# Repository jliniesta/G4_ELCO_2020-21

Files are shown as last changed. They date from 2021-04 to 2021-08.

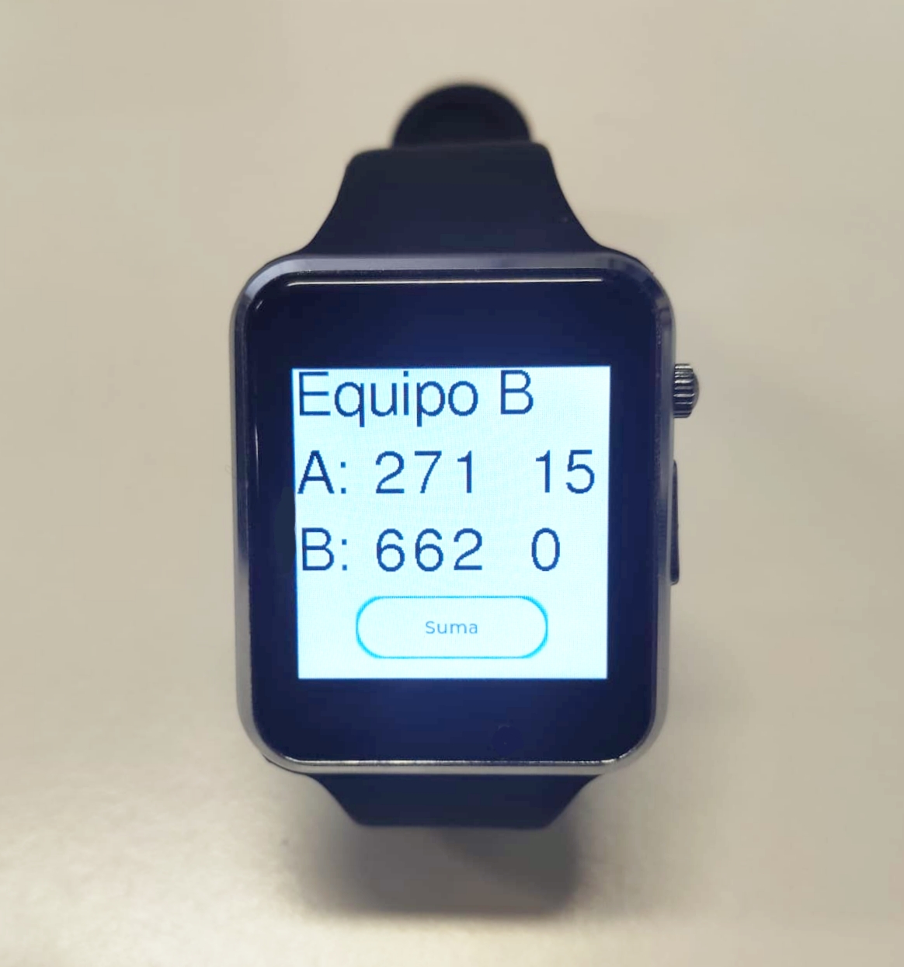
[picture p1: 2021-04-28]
Prototipo/Resultado final prototipo/reloj_TTGO_T-Watch.jpg

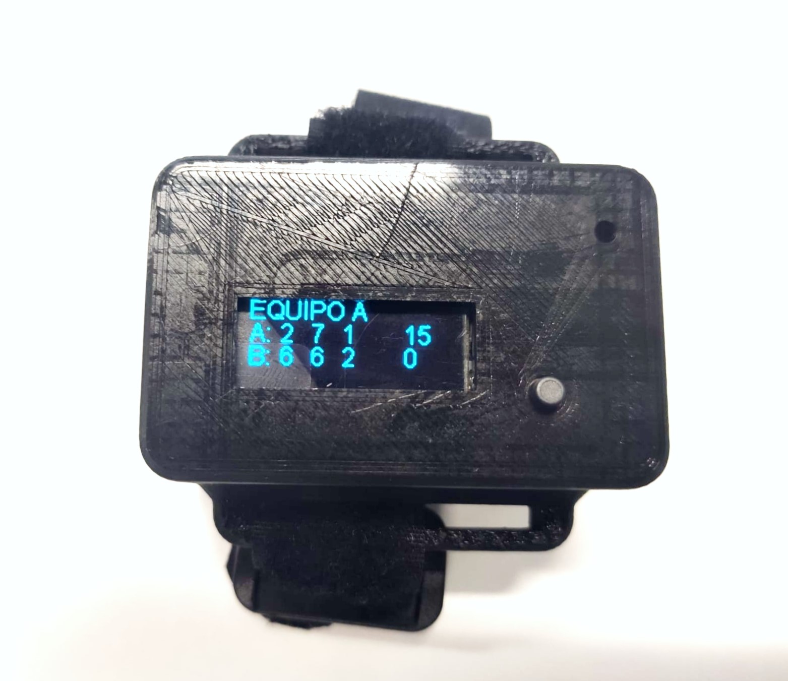
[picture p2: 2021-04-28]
Prototipo/Resultado final prototipo/reloj_heltec.jpg

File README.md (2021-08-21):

# PADEL WATCH

https://padel-watch.webnode.es/

https://blogs.upm.es/tfb/contador-de-pulsos-padel/

Proyecto del grupo 4 de la asignatura de Electrónica de Consumo (ELCO)

ETSIT - UPM

# Funcionamiento
> Marcador para poder contar todos los puntos de un partido de pádel.
> Cada pareja, dispondrá de al menos un reloj que con un pequeño botón,
> que permitirá incrementar los puntos. De forma, que cuando una pareja
> gane un punto, lo único que tendrá que hacer es pulsar el botón y el
> marcador se actualizará con el nuevo resultado.

### Integrantes
- Javier López Iniesta Díaz del Campo
- Fernando García Gutiérrez
- Ivan Martín Cantón
- Iñigo Montesino Sarmiento
- Luis de Pablo Beltrán

### Licencia
Copyright 2021 Padel Watch. \
All rights reserved.

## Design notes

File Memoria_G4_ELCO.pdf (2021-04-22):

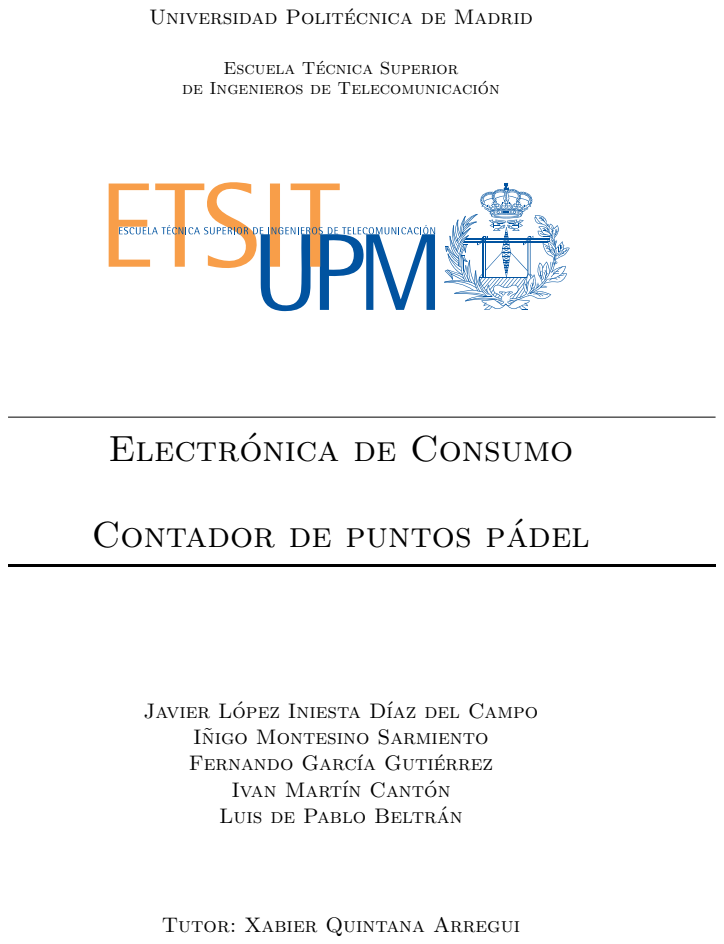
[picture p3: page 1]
Javier Lopez Iniesta D ´; íaz del Campo

Universidad Politecnica de Madrid ´

Escuela Tecnica Superior ´

de Ingenieros de Telecomunicacion´

Electronica de Consumo ´

Contador de puntos padel

Inigo Montesino Sarmiento ˜

Fernando García Gutierrez ´

Ivan Martín Canton´

Luis de Pablo Beltran´

Tutor: Xabier Quintana Arregui

Contador de puntos pádel

## Índice

1. Introducción | 2
2. Idea de producto | 2
3. Prototipo | 3
4. Resultado final del prototipo | 6
5. Producto final | 7
6. Manual de usuario | 10
7. Pagina web | 10

## 1. Introducción

Este proyecto ha sido realizado por 5 alumnos de la asignatura de Electrónica de Consumo del Itinerario de Sistemas Electrónicos del Grado en Ingeniería de Tecnologías y Servicios de Telecomunicación. El objetivo de esta asignatura es realizar un producto que pueda satisfacer una necesidad, que sea atractivo, funcional, y orientado al consumo (más de 10.000 unidades fabricadas). Además, deberá ser viable económicamente.

En este proyecto, se ha trabajado como si fuera una pequeña empresa de ingeniería, pasando por todas las fases de diseño y comercialización del producto. En primer lugar, se desarrollará la idea de servicio y el problema a resolver. Posteriormente, se explicará el prototipo realizado, detallando su completo funcionamiento hardware y software. Por último, presentaremos nuestro diseño final orientado a la producción masiva.

Estos tres pasos los complementaremos con detalles técnicos y orientados a la experiencia del usuario final, redactando su manual de instrucciones respectivo y una pagina web que suponga para el cliente el lugar de adquisición del producto o donde obtener un servicio post-venta.

## 2. Idea de producto

En los últimos años, el pádel es el deporte que más está creciendo en España, tanto a nivel amateur como a nivel profesional. Dentro de este deporte, hemos detectado la necesidad de los usuarios de contar los puntos de una manera más fácil y sin que sea necesario hacer mucho uso de la memoria evitando tanto malentendidos como incertidumbres en el desarrollo del partido.

Por ello, desde nuestra empresa llamada Padel Watch, proponemos crear un marcador para poder contar todos los puntos de un partido de pádel. Cada pareja, dispondrá de una pulsera que contará con un pequeño botón, para incrementar los puntos. De esta forma, cuando una pareja gane un punto, lo único que tendrá que hacer es pulsar el botón y el marcador se actualizará con el nuevo resultado.

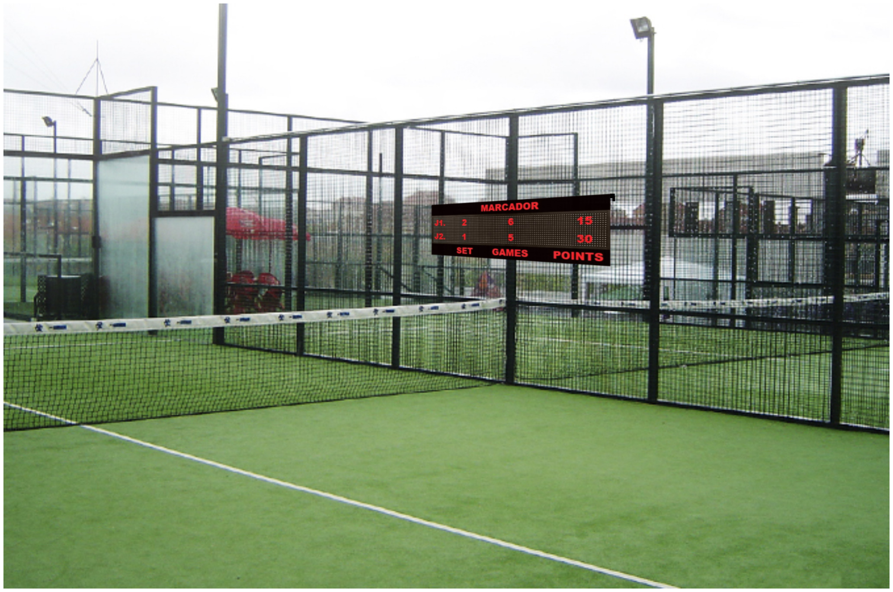
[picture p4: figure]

Figura 1: Marcador pádel

## 3. Prototipo

### 3.1. Materiales y componentes

Para nuestro prototipo se han utilizado la siguiente lista de materiales:

Relojes:

- ESP32 (WiFi Kit 32).
- LilyGO ©TTGO T-Watch-2020 ESP32.

Pantalla: LilyGO TTGO T5 V2.3 ESP32 - with 2.13 inch E-paper E-ink.

Batería: E603048P 4121 (900 mAh).

Pulsador: mcm t05.

Resistencia de 1 kΩ.

Filamento PLA 1.75 mm de color negro.

Correa de velcro

ProtoBoard

En primer lugar, el ESP32 utilizado, ha sido el modelo “WiFi Kit 32” (https://heltec.org/project/wifi-kit-32/) [1], un microcontrolador que cuenta con un display OLED integrado de 0, 96 pulgadas. Además, cuenta con conexión WiFi y Bluetooth.

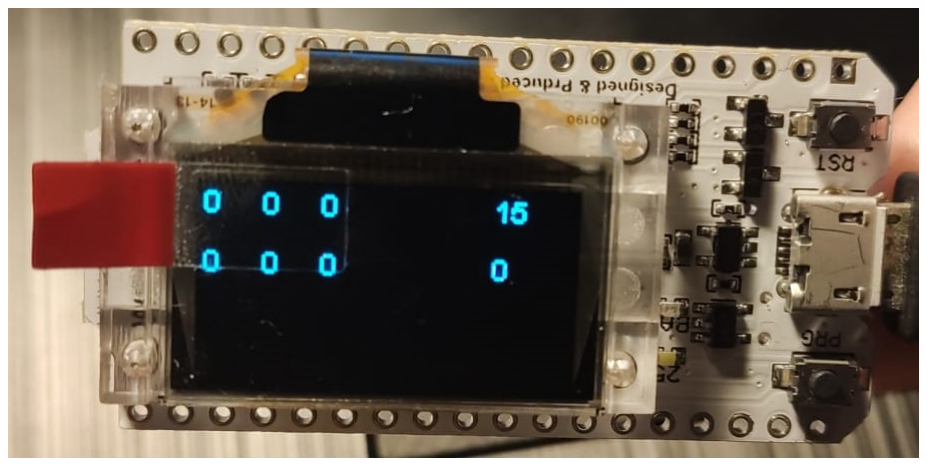
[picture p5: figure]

Figura 2: ESP32 - WiFi Kit 32

Dicho microcontrolador, ha sido adquirido por la Universidad Politécnica de Madrid y cedido para este proyecto. Se puede encontrar fácilmente en el mercado por un precio de alrededor de 20 e. Para poder alimentar el ESP32, necesitamos disponer de una batería. Para ello, hemos elegido una de 900 mAh, concretamente el modelo “E7E6H-D60-1”. (https://www.ebay.es/itm/3-7V-900mAh-603048-Li-po-Polymer-li-ion-Rechargeable-Battery-For-GPS-PSP-mp3-PAD-/111946070348)

Para poder aumentar los puntos desde el ESP32, hemos tenido que incorporar un pulsador “mcm t05”, colocado en el pin 12 junto con una resistencia de 1 kΩ colocada en paralelo y todo ello trabajando sobre la protoboard. Además, para ver como queda en la muñeca le hemos añadido una correa de velcro.

En segundo lugar, también se ha utilizado un reloj programable de la marca LilyGO, que puede interaccionar con el entorno a través de distinto sensores. El modelo elegido, ha sido el “LilyGO TTGO T-Watch-2020 ESP32” (http://www.lilygo.cn/prod_view.aspx?TypeId=50053&Id=1290&FId=t3:50053:3) [2]. Este reloj se puede programar con Arduino, Scratch, micropython, pictoblox, etc.

El reloj cuenta con una pantalla táctil LCD de 1, 54 pulgadas. En adicción, posee una batería de Litio, acelerómetro, vibración, altavoz y sensor de infrarrojos. Se puede interconectar mediante WiFi y Bluetooth. Se puede encontrar en el mercado por unos 25 e. El reloj ha sido cedido por nuestro tutor, Xabier Quintana Arregui.

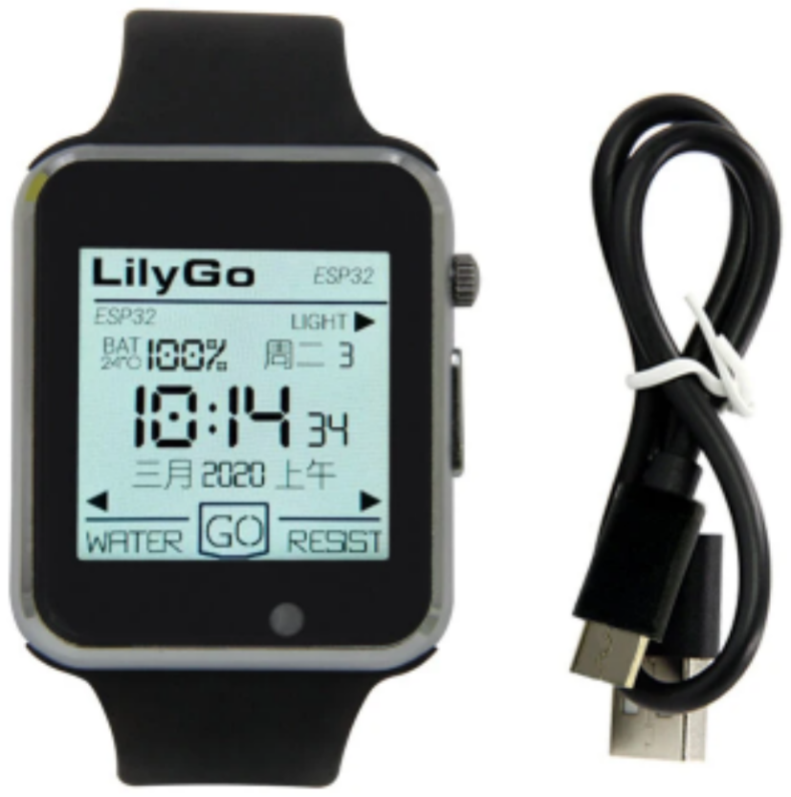
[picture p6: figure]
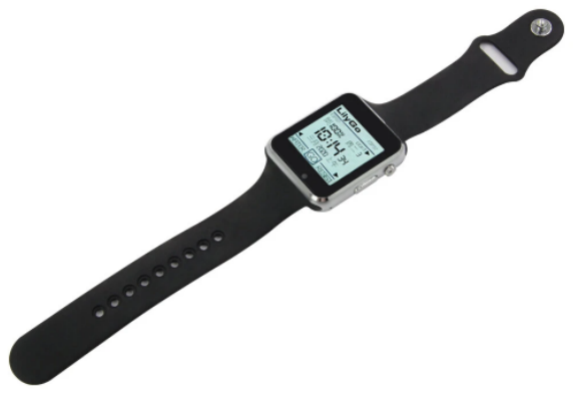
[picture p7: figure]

(a) (b)

Figura 3: LilyGO TTGO T-Watch-2020 ESP32 (a) Pantalla y cableado (b) Reloj completo.

Además, se dispone de una pantalla también de la marca LilyGO (“LilyGO TTGO T5 V2.3 ESP32”) (http://www.lilygo.cn/prod_view.aspx?TypeId=50031&Id=1149&FId=t3:50031:3) [3], de 2,13 pulgadas de tinta electrónica, con un microcontralador basado en un ESP32. Dispone de conexión WiFi y Bluetooth, así como de una batería.

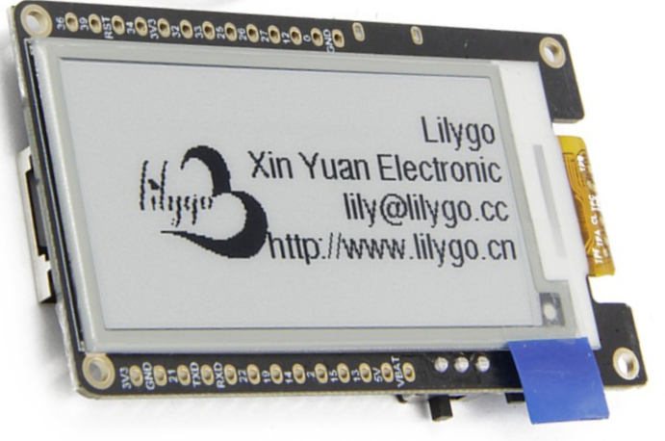
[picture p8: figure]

Figura 4: LilyGO TTGO T5 V2.3 ESP32

### 3.2. Esquemáticos

La Figura 5 se muestra los esquemáticos del prototipo del reloj, formado por el ESP32, la batería, un pulsador y una resistencia. Dicho esquemáticos han sido realizados mediante el programa Fritzing [4].

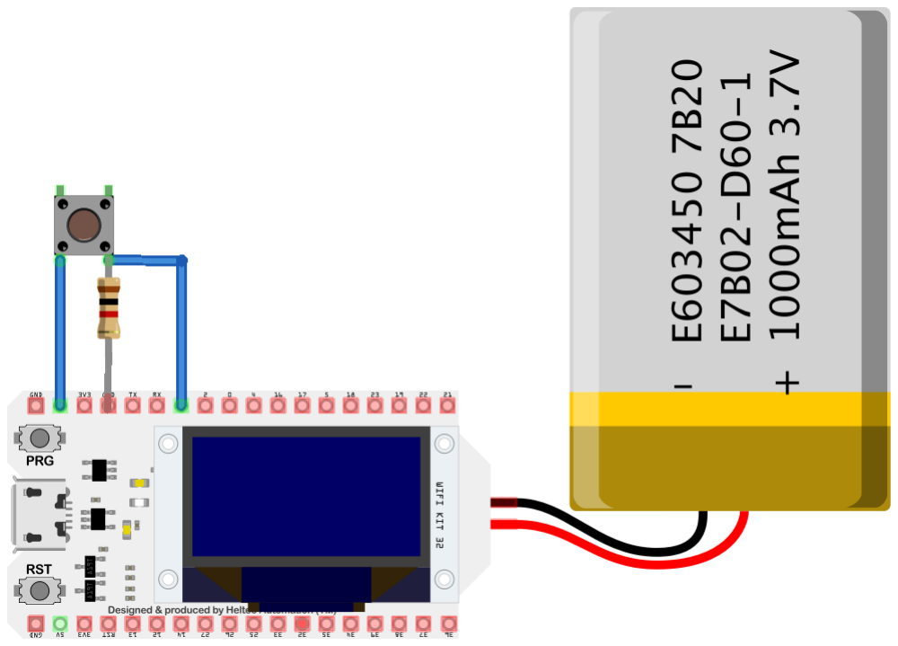
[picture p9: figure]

Figura 5: Esquemáticos del reloj con el ESP32

### 3.3. Diseño e implementación software

Reloj 1 | Reloj 2

## Pantalla

Figura 6: Esquema de la comunicación entre los dispositivos

### 3.4. Diseño mecánico y modelo 3D

A continuación, en la Figura 7 se muestra las carcasas del marcador y del reloj. Para su diseño e implementación, se ha usado la herramienta de FreeCAD 0.18 [5].

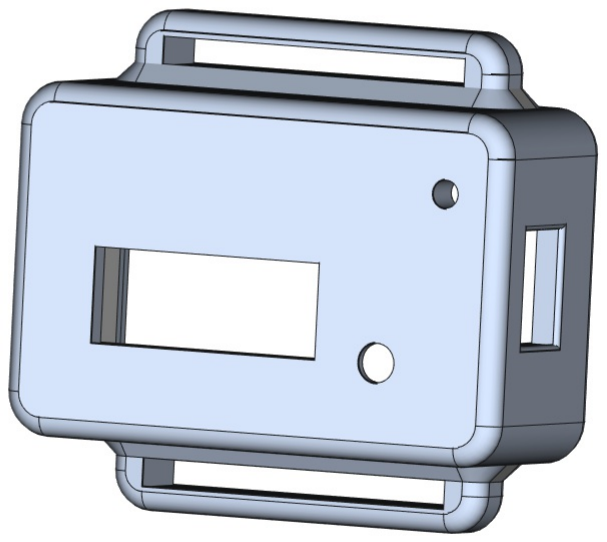
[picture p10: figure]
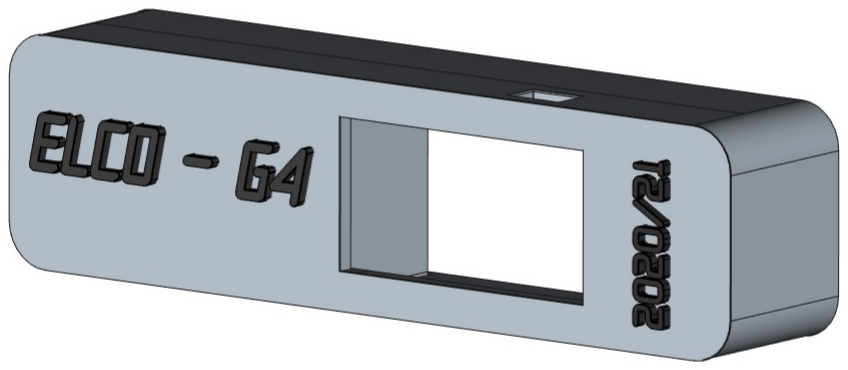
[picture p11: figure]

(a) Marcador | (b) Reloj

Figura 7: Modelo 3d de las carcasas

Además hemos diseñado las siguientes tapas para proteger la parte trasera tanto del reloj como del marcador.

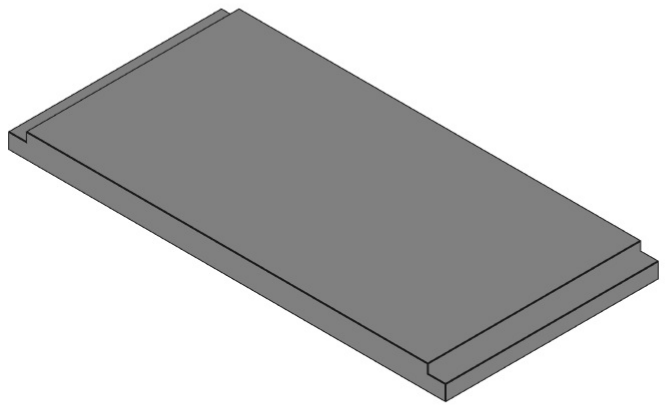
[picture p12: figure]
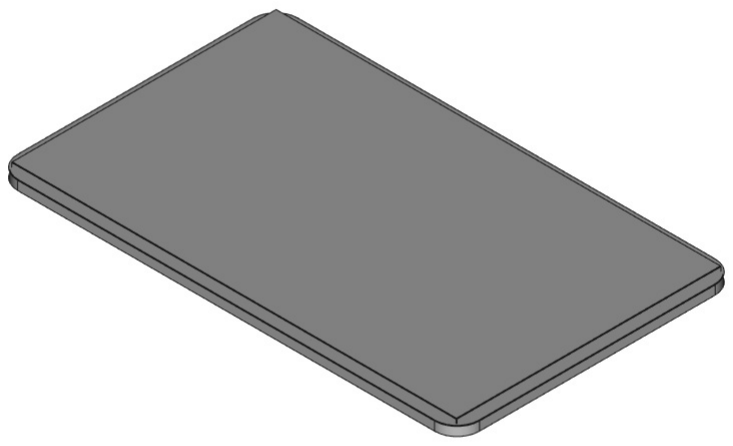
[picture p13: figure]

(a) Marcador | (b) Reloj

Figura 8: Modelo 3d de las tapas de las carcasas

Las carcasas las hemos fabricado mediante una impresora 3D de la ETSIT-UPM. Para la sujeción del reloj le añadiremos la cinta de velcro.

## 4. Resultado final del prototipo

Poner imágenes del resultado final del prototipo.

## 5. Producto final

Tras comprobar que el prototipo creado ha sido desarrollado satisfactoriamente, procedemos a especificar como será nuestro producto final.

El producto final constará de dos relojes LilyGO TTGO T-Watch-2020 ESP32 [2] y un marcador LED electrónico ”VEVOR”[6]. La idea será tener dos relojes igualmente programados que constan con un botón para sumar puntos y otro para deshacer la acción anterior. Ambos estarán conectados entre ellos mediante WiFi y a su vez conectados con el marcador central, que mostrará el resultado del partido constantemente.

### 5.1. Materiales y Suministradores

Como hemos especificado anteriormente, solo contaremos con la necesidad de obtener:

Reloj: LILYGO® TTGO T-Watch-2020 ESP32

Marcador: Rótulo LED Electrónico ”VEVOR”

En primer lugar, el reloj será el mismo que usamos en el prototipo. No profundizaremos en sus especificaciones ya que lo hicimos en la parte del prototipo. Sin embargo, debemos de mencionar a nuestros suministradores, que serán directamente la pagina web www.banggood.com. Además, hemos alcanzado con ellos un descuento por volumen de aproximadamente el 25 % lo que hará que el precio unitario de cada reloj sea de 19e.

Por otro lado tenemos el marcador que pertenece a la marca VEVOR. Es un marcador que adquiriremos a través del distribuidor Amazon, con el que hemos negociado un descuento por volumen de 25 %.

### 5.2. Almacenaje, distribución y medios de venta

Para el producto que vamos a comercializar será necesario tener un sitio para poder llevar a cabo la actividad de embalaje, carga del software y almacenamiento de productos terminados listos para su envío. Por lo tanto para reducir costes, alquilaremos durante nuestro ejercicio económico un espacio coworking [7], en la zona centro de Madrid, a razón de 5.000€ anuales.

La distribución del producto la haremos mediante envíos y servicio de paquetería tradicional, llegando a distintos acuerdos con empresas de mensajería.

Como medio de venta principal contaremos con nuestra página web donde el cliente directamente podrá ejecutar de una manera sencilla la compra. A su vez consideramos entrar en webs externas (Amazon e Ebay) para poder llegar a mas público y poder aumentar el volumen de ventas.

### 5.3. Empaquetado

Con el fin del transporte del producto en perfectas condiciones hemos diseñado una caja para su empaquetado. Dependiendo del paquete de venta elegido, la caja contendrá en su interior los productos, así como un manual de instrucciones. La estimación del coste de empaquetado será de 1 epor unidad. Las dimensiones de la caja serán:

Para los paquetes con marcador: 110 cm x 50 cm x 20 cm

Para los paquetes sin marcador: 30 cm x 30 cm x 30 cm

La Figura 9 muestra el empaquetado del paquete de 2 relojes más marcador.

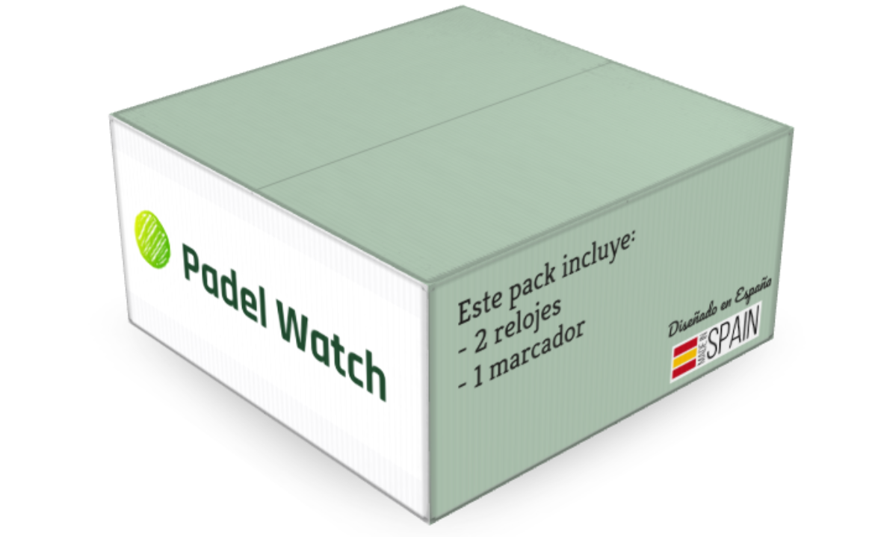
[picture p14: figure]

Figura 9: Empaquetado

### 5.4. Estudio costes y precios de venta

Para realizar el estudio y la viabilidad económica de la empresa, en primer lugar, se ha realizado una estimación del número total de unidades vendidas de nuestros productos. Tendremos tres tipos de productos que el cliente podrá comprar: el paquete de marcador y dos relojes, el paquete de cuatro relojes y el paquete de dos relojes. Estimamos que venderemos 10 000 paquetes, siendo el 75 % de ellos el primero, y un 12,5 % el segundo y tercero.

Paquetes de venta | Estimación unidades vendidas
2 relojes + marcador 2 relojes extra 4 relojes | 7 500 1 250 1 250
Total unidades: | 10 000

Tabla 1: Estimación ventas

Posteriormente, se considerarán los costes materiales de nuestros productos. Como es lógico, llegaremos a acuerdos con los proveedores de relojes y de pantallas para obtener un descuento por volumen de compra de alrededor del 25-30 %. Los otros dos gastos adicionales a tener en cuenta serán los materiales de embalajes, estimados en 1, 00 e por cada paquete, y el lugar donde tendremos nuestra actividad económica, que supondrán los ya mencionados 5 000 e anuales.

En la Tabla 2 se muestran la estimación de costes materiales.

Costes materiales
Producto | Nº de unidades | Precio / unidad | Coste total
Relojes Marcadores Embalaje | 22 500 7 500 10 000 | 19, 00 e 50, 00 e 1, 00 e | 427 500 e 375 000 e 10 000 e
| Total: | | 812 500 e
| Coworking (coste anual): | | 5 000 e
| Total gastos materiales: | | 817 500 e

Tabla 2: Costes materiales

Los siguientes gastos importantes que supondrán para la empresa será la contratación del personal. Hemos estimado que necesitaremos personal para realizar dos labores concretas: la carga del software en cada reloj y el preparado y embalado de todos los paquetes, junto con la responsabilidad de entregarlo a la empresa de paquetería. La carga de trabajo medida en tiempo de estas dos labores será de 6 minutos por cada carga de programa en el reloj y de 30 minutos de embalaje por cada paquete. El perfil de trabajador que buscamos para la carga del software será un diplomado universitario, ingeniero técnico o equivalente, que supondrá para la empresa un gasto total de 19, 36 e por hora trabajada. Para la realización del embalaje y la gestión del envío requeriremos un perfil con un nivel de formación F.P.II-Graduado, escolar o equivalente que supondrán para la empresa un gasto de 16, 00 e por hora trabajada.

Costes personales
Función | Unidades | Tiempo/labor (h) | Total horas | Precio/hora | Coste
Cargar programas Embalaje | 22 500 relojes 10 000 paquetes | 0, 1 0, 5 | 2 250 5 000 | 19, 36 e 16, 00 e | 43 560 e 80 000 e
| | | | Total: | 123 560 e

Tabla 3: Costes personal

En cuanto a los ingresos, como es lógico, cada uno de los paquetes descritos anteriormente tendrá su respectivo precio. Para calcularlo, lo primero que hacemos es estimar cual es el precio por unidad que supone para nosotros cada uno de estos paquetes, y le aplicaremos un 40 % de margen de beneficio. Adicionalmente, para dar el precio final del producto debemos aplicarle el 21 % de I.V.A.

Paquete de venta | Coste/paquete (e) | Precio (sin IVA) | IVA | Precio final
2 relojes + marcador 2 relojes extra 4 relojes | 101, 86 e 51, 86 e 89, 86 e | 142, 60 e 72, 60 e 125, 80 e | 29, 95 e 15, 25 e 26, 42 e | 172, 54 e 87, 84 e 152, 22 e

Tabla 4: Coste producto final

## 6. Manual de usuario

En el manual de usuario se muestran las especificaciones técnicas del reloj y del marcador de los productos comercializados por Padel Watch, asi como las advertencias de seguridad a seguir. Además, se muestra su funcionamiento y una sección de posibles preguntas que le pueden surgir a los usuarios. En el siguiente link de github puede consultar el manual:

Pinche aquí para ver el manual (https://github.com/iniesta99/G4_ELCO_2020-21/blob/main/Dise%C3%B1o%20final/Manual_de_usuario_G4_ELCO.pdf)

## 7. Pagina web

La pagina web ha sido diseñada con una plantilla de Webnode. En ella contiene información básica sobre el diseño final del producto, su funcionamiento. Además se muestran los productos que serán comercializados. Además se muestra información sobre los componentes del grupo y contacto.

https://padel-watch.webnode.es/

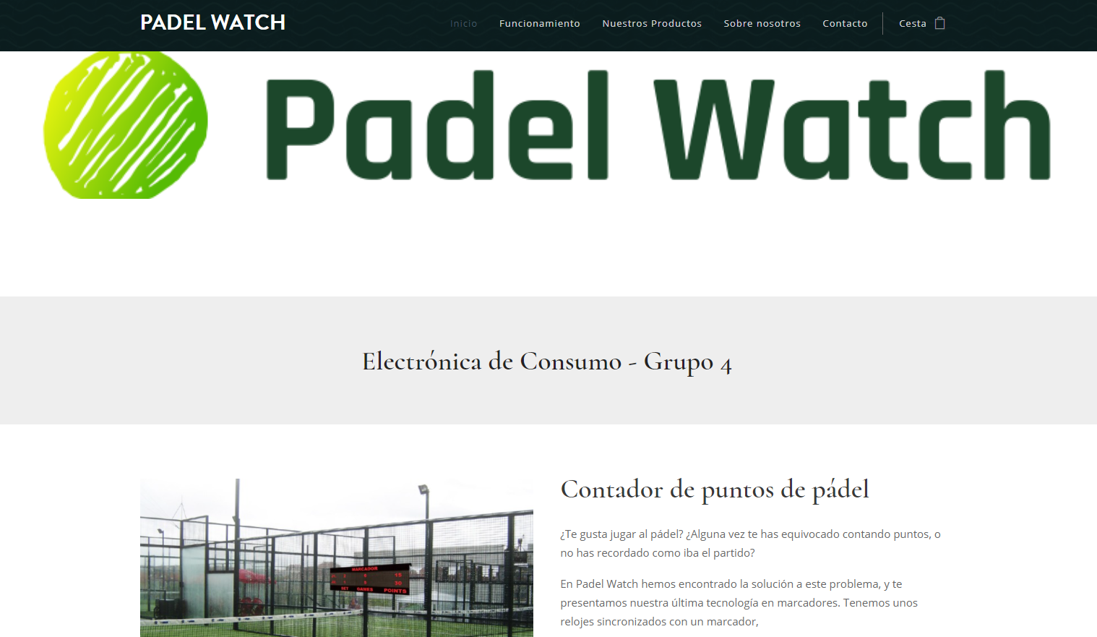
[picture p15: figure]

Figura 10: Página Web

## Referencias

[1] Heltec, “WiFi Kit 32,” 2019. [En línea]. Diponible en: https://heltec.org/project/wifi-kit-32/. (https://heltec.org/project/wifi-kit-32/) Accedido: 21-abr-2021.
[2] LILYGO, “TTGO T-Watch-2020 ESP32 Main Chip 1.54 Inch Touch Display Programmable Wearable,” 2020. [En línea]. Diponible en: http://www.lilygo.cn/prod_view.aspx?TypeId=50053&Id=1290&FId=t3:50053:3. (http://www.lilygo.cn/prod_view.aspx?TypeId=50053&Id=1290&FId=t3:50053:3) Accedido: 18-abr-2021.
[3] LILYGO, “TTGO T5 V2.3 2.13 Inch E-Paper Screen New Driver Chip,” 2020. [En línea]. Diponible en: http://www.lilygo.cn/prod_view.aspx?TypeId=50031&Id=1149&FId=t3: 50031:3. (http://www.lilygo.cn/prod_view.aspx?TypeId=50031&Id=1149&FId=t3:50031:3) Accedido: 21-abr-2021.
[4] “Fritzing,” 2021. [En línea]. Diponible en: https://fritzing.org/. Accedido: 10-abr-2021.
[5] “Fritzing,” 2021. [En línea]. Diponible en: https://www.freecadweb.org/. Accedido: 15-mar-2021.
[6] Amazon, “VEVOR Rótulo LED Electrónico,” 2021. [En línea]. Diponible en: https://www.amazon.es/VEVOR-Electr%C3%B3nico-Desplazamiento-Publicitaria-Publicidades/dp/B08P2T2TVN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 (https://www.amazon.es/VEVOR-Electr%C3%B3nico-Desplazamiento-Publicitaria-Publicidades/dp/B08P2T2TVN) . Accedido: 21-abr-2021.
[7] “Goya smart-coworking,” 2021. [En línea]. Diponible en: https://www.goyacoworking.es/tarifas-coworking-madrid/. (https://www.goyacoworking.es/tarifas-coworking-madrid/) Accedido: 12-mar-2021.

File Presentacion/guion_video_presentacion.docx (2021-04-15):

GUIÓN VIDEO PRESENTACIÓN:

1) Presentar el producto

2) ¿Que ha hecho cada uno?

3) Programación

4) Carcasas 3D

5) El coste

6) Demo (al final para mantener la atención de la gente)

15 minutos en total:

-Plano introductorio de la universidad por fuera (5 segundos)

-Quienes somos y que hacemos aqui (30 segundos)

“Hola buenas, somos el grupo 4 de elco, nuestros nombres son tal, tal y tal ...”

-Plano de una o dos personas explicando necesidad y la idea de negocio (1 minuto)

“En los últimos años, el pádel es el deporte que más está creciendo en España, tanto a nivel amateur como a nivel profesional. Dentro de este deporte, hemos detectado la necesidad de los usuarios de contar los puntos de una manera más fácil y sin que sea necesario hacer mucho uso de la memoria evitando tanto malentendidos como incertidumbres en el desarrollo del partido.

Por ello, desde nuestra empresa llamada Padel Watch, proponemos crear un marcador para poder contar todos los puntos de un partido de pádel. Cada pareja, dispondrá de una pulsera que contará con un pequeño botón, para incrementar los puntos. De esta forma, cuando una pareja gane un punto, lo único que tendrá que hacer es pulsar el botón y el marcador se actualizará con el nuevo resultado.”

-Explicar en que consiste el producto desarrollado. (1 minuto 30 segundos)

- Salir hablando una persona con los prototipos desarrollados (esp32, pantalla, lily watch) y explicar que en que consiste. Además contar los suministradores de los productos, donde hemos comprado cada cosa, etc.

-Organigrama (1 minuto)

-Una presentación hablando de los distintos departamentos y funciones

(es importante comentar la horizontalidad del trabajo y el estar en contacto todos con todos)

-Tras el organigrama, cada uno sale en pantalla (o con una presentación) explicando en que ha consistido su trabajo y que ha aportado (alrededor de un minuto por pesona) (10 minutos)

- Desarrollo SW (Iván, Fer y Luis)

- Botón y soldaduras de los distintos componentes (Iván, Fer y Luis)

- Carcasas 3D (Javi)

- Precio producto, números, etc (Iñígo, Javi)

- Pagina Web (Iñígo, Javi)

-Demo (1 minuto)

- Salir 4 integrantes jugando al padel y probando el padel watch.

-Visión de futuro y producto final: detallar los aspectos en los que se mejoraría el producto final. (30 segundos)

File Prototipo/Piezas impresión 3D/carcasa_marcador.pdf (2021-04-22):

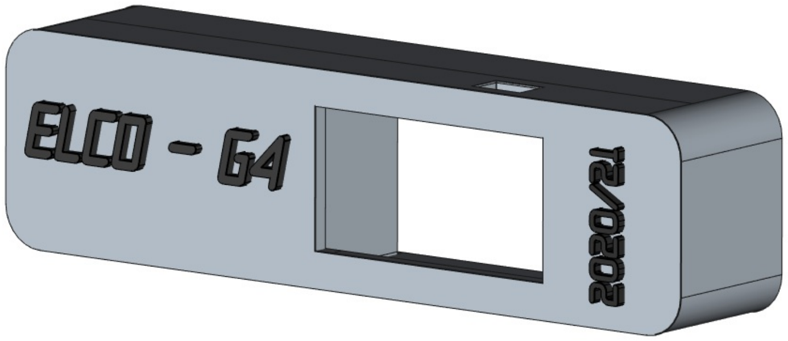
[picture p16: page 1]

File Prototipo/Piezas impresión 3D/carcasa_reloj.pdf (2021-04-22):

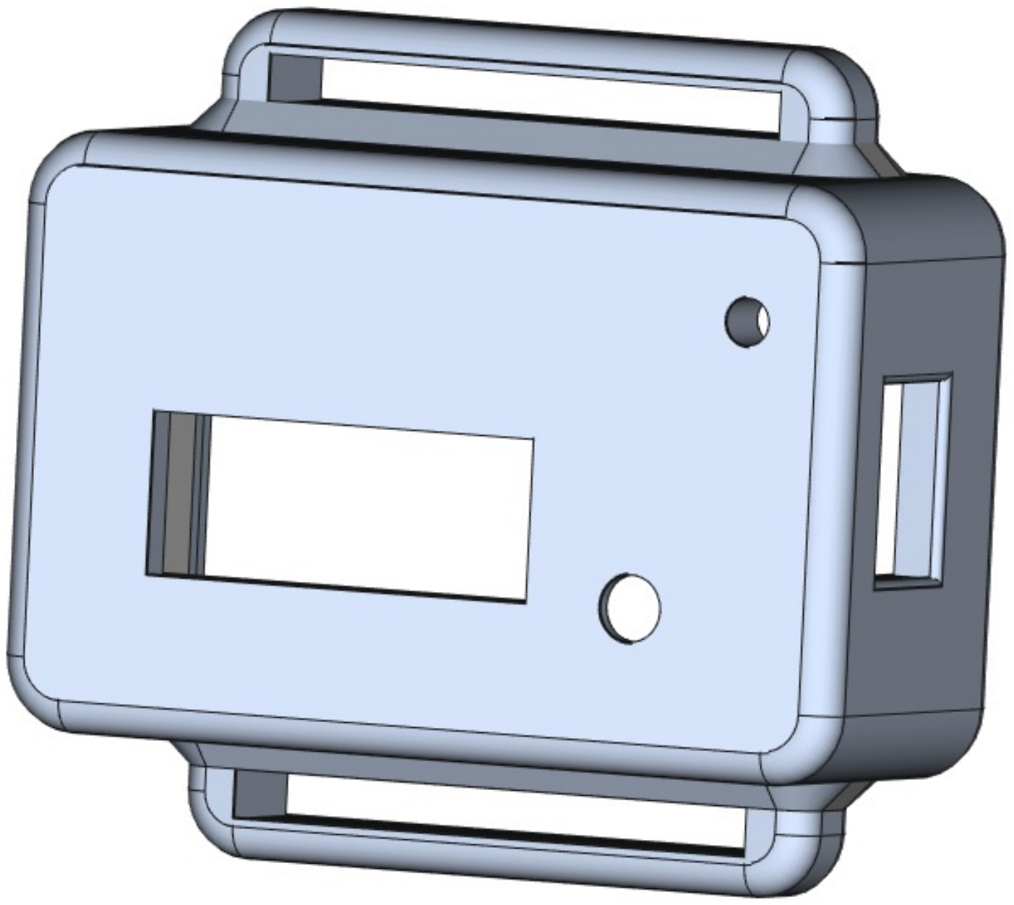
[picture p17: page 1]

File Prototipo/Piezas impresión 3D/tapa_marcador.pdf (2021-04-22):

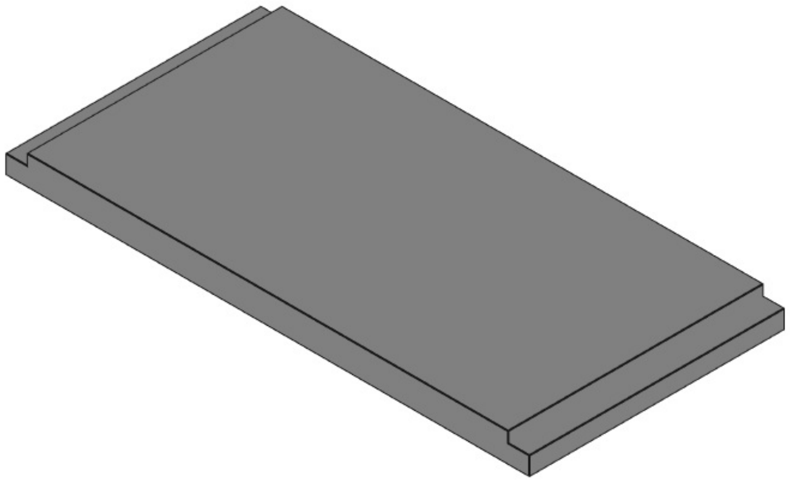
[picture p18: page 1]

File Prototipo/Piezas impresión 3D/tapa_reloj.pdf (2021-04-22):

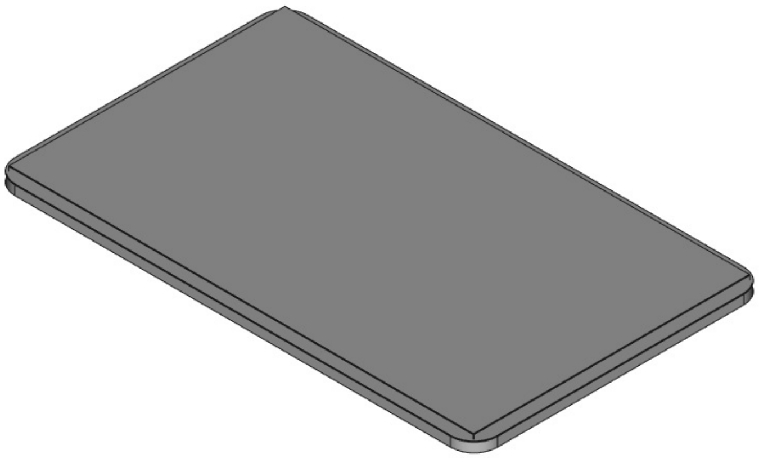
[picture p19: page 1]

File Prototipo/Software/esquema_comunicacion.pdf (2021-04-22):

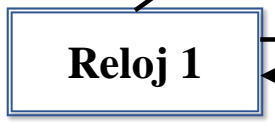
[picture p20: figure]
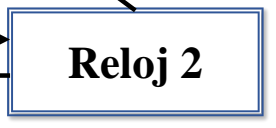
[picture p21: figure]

Reloj 1 | Reloj 2

Pantalla

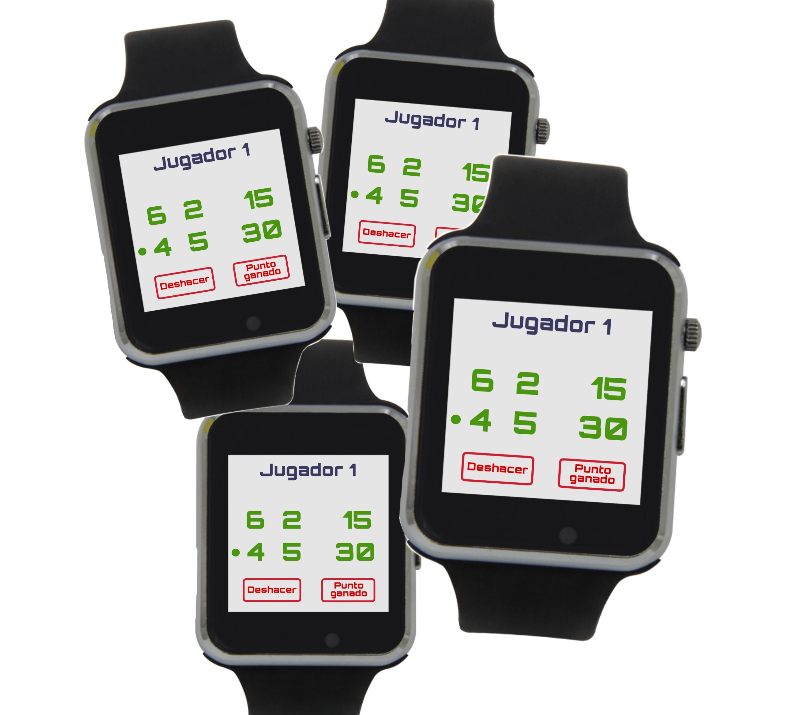
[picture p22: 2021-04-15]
Diseño final/Diseño mecanico/4relojes.png

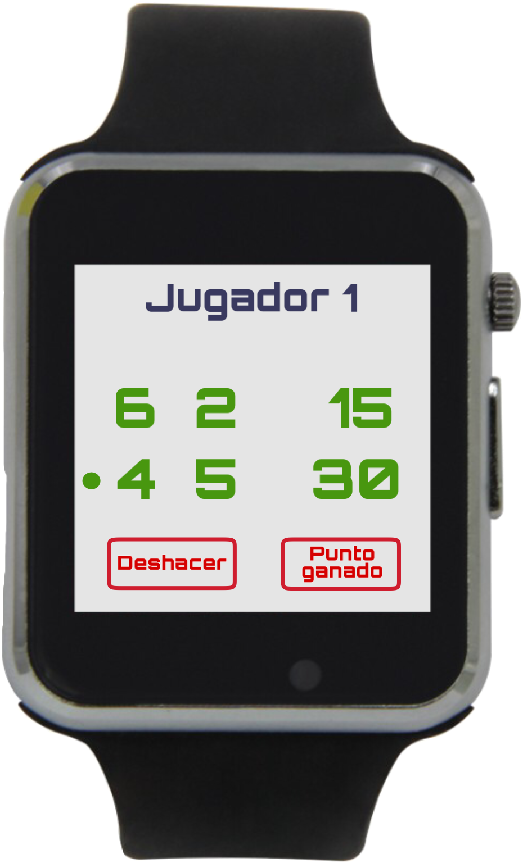
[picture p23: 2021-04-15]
Diseño final/Diseño mecanico/reloj.png

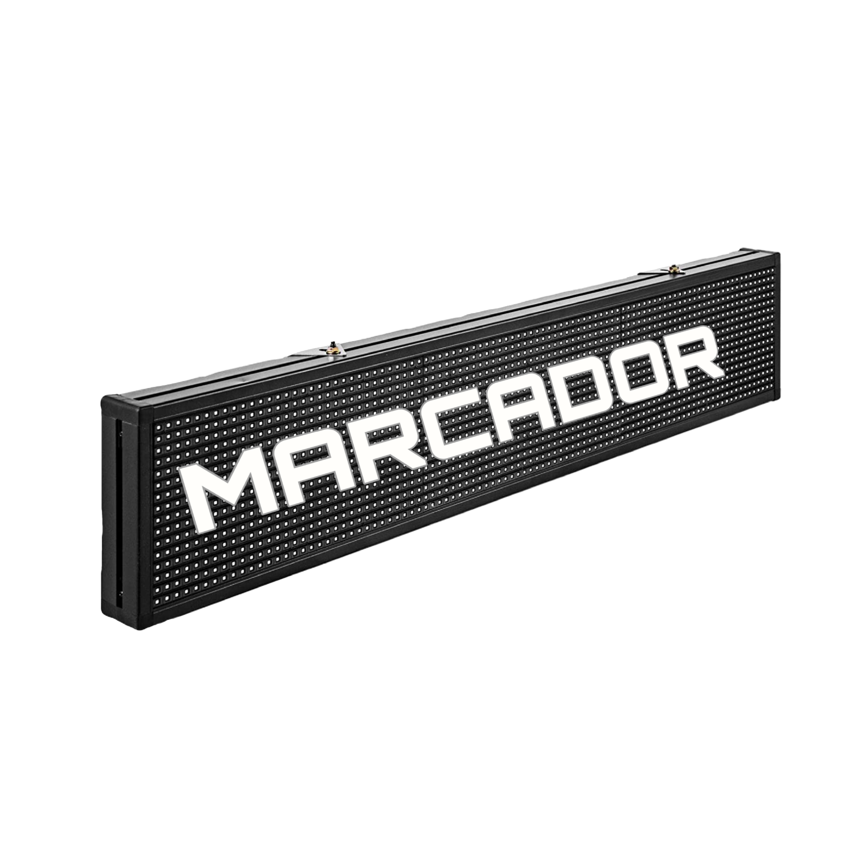
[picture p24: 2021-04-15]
Diseño final/Diseño mecanico/marcador.png

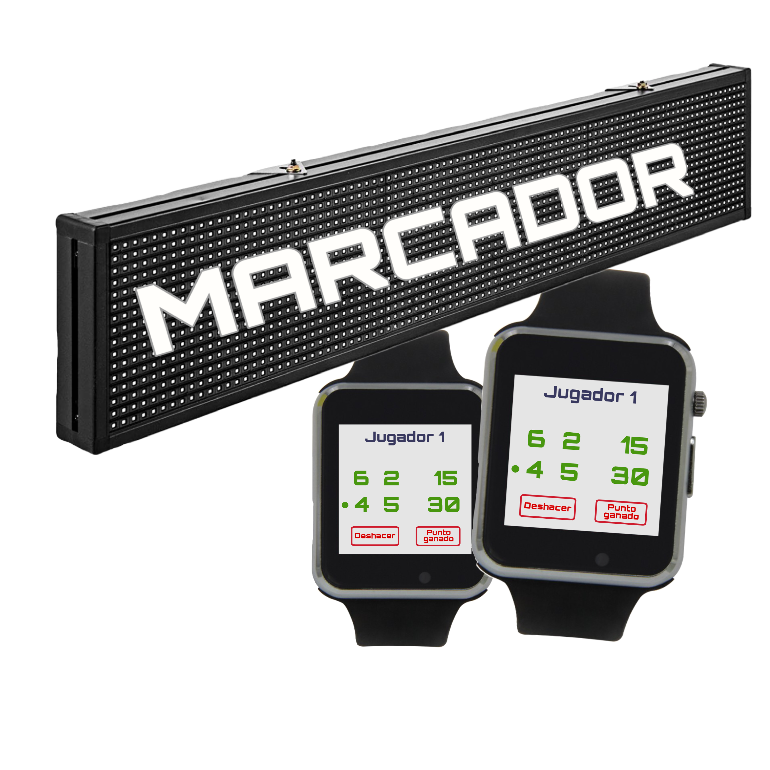
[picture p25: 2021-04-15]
Diseño final/Diseño mecanico/marcador_2relojes.png

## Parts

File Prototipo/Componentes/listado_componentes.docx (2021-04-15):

LISTADO DE COMPONENTES:

# LILYGO® TTGO T-Watch-2020 ESP32

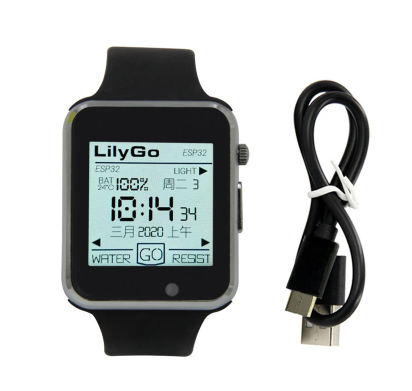
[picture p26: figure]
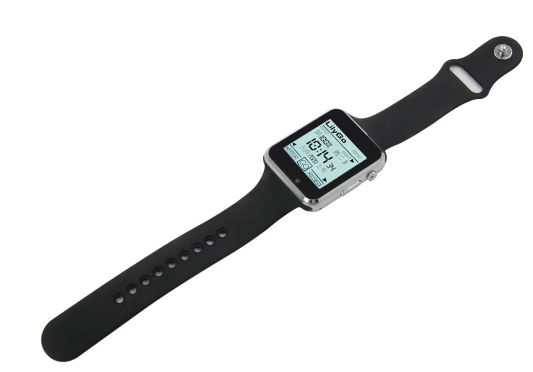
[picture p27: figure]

# Pagina web del fabricante:

# http://www.lilygo.cn/prod_view.aspx?TypeId=50053&Id=1290&FId=t3:50053:3

More Information:

- https://github.com/Xinyuan-LilyGO/TTGO_TWatch_Library
- https://t-watch-document-en.readthedocs.io/en/latest/introduction/product/2020.html#description

Tutorial para principiantes:

https://www.youtube.com/watch?v=msLVt6-G_Kg&ab_channel=LILYGO

Precios:

- Banggood: 26,21 €
  - https://banggood.app.link/RSK4O1YeHeb
- Aliexpress: 22,30 €
  - https://es.aliexpress.com/i/4000971508364.html
- Amazon: 50,89 €
  - https://www.amazon.es/dp/B08LKGS2CF/ref=cm_sw_em_r_mt_dp_QTZVCDNSTGZS4PBCCR42
- Pagina holandesa (Xabi):

Pines:

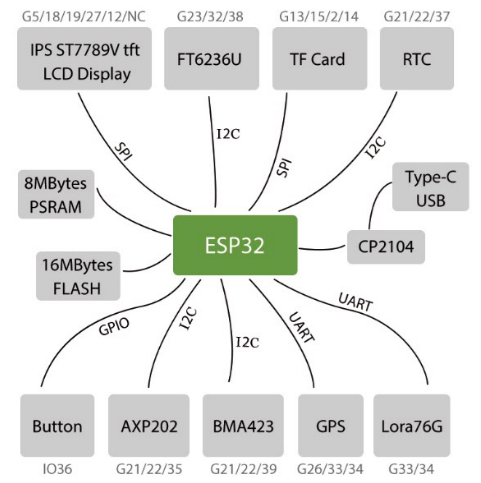
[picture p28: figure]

INSTALACIÓN SOFTWARE PARA LILYGO WATCH:

- Install the Arduino IDE (https://www.arduino.cc/en/Main/Software). Note: Later instructions may not work if you use Arduino via Flatpak.
- Download a zipfile from github using the "Download ZIP" button and install it using the IDE ("Sketch" -> "Include Library" -> "Add .ZIP Library...", OR:
- Clone this git repository into your sketchbook/libraries folder. For more info, see https://www.arduino.cc/en/Guide/Libraries

# ESP32

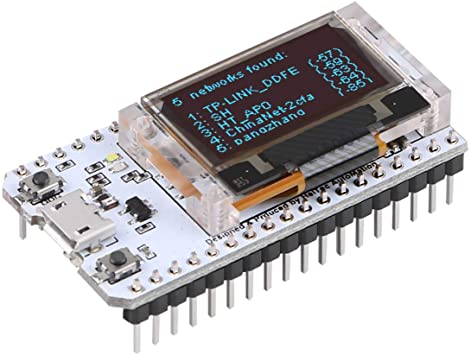
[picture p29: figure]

Donde comprar:

- https://www.amazon.es/Desarrollo-Pantalla-Pulgadas-Arduino-Compatible/dp/B07428W8H3

Especificaciones técnicas (datasheets) y otro sitio donde comprar:

- https://heltec.org/project/wifi-kit-32/

Precios:

- Heltec:10$
- Amazon: 50 €

# PANTALLA:

# LilyGO TTGO T5 V2.3 ESP32 - with 2.13 inch E-paper E-ink

# Link de compra:

- https://www.tinytronics.nl/shop/en/platforms/ttgo/lilygo-ttgo-t5-v2.3-esp32-with-2.13-inch-e-paper-e-ink

# Especificaciones Técnicas:

- http://www.lilygo.cn/prod_view.aspx?TypeId=50031&Id=1149&FId=t3:50031:3

Github:

- https://github.com/Xinyuan-LilyGO/LilyGo-T5-ink-series

Precios:

- TinyTronics:14.5$
- Aliexpress: 11.49-13.14 €

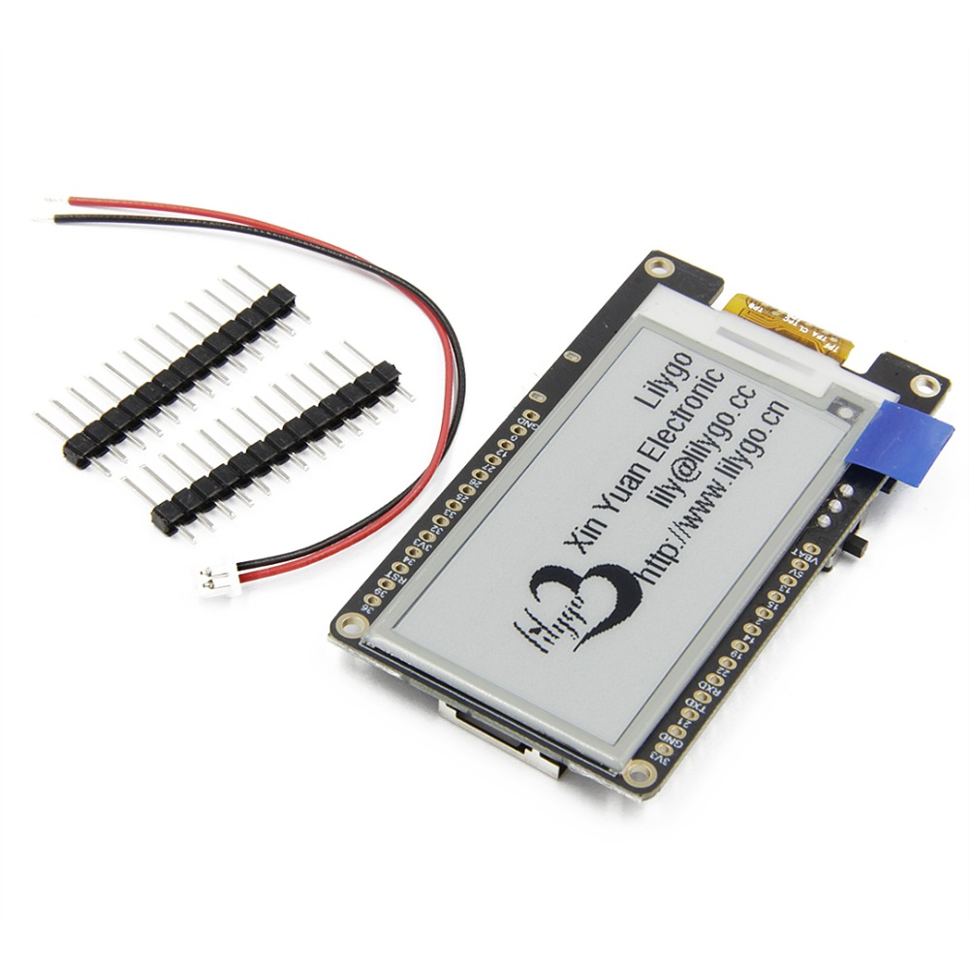
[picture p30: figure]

# BATERÍA:

Máximo de puntos por juego:

- 3 sets
- 12 juegos + tie break (22 puntos) / set
- 10 puntos como maximo por juego
- Total: 426 puntos (refrescos)

Cada refresco la pantalla consume 26,4 mW por refresco

En total como mucho en un partido se consumiria 11,24 W

E603048P 4121: Batería de 900 mAh

E7E6H-D60-1

Links de compra:

Ebay: 6,99 €

https://www.ebay.es/itm/3-7V-900mAh-603048-Li-po-Polymer-li-ion-Rechargeable-Battery-For-GPS-PSP-mp3-PAD-/111946070348

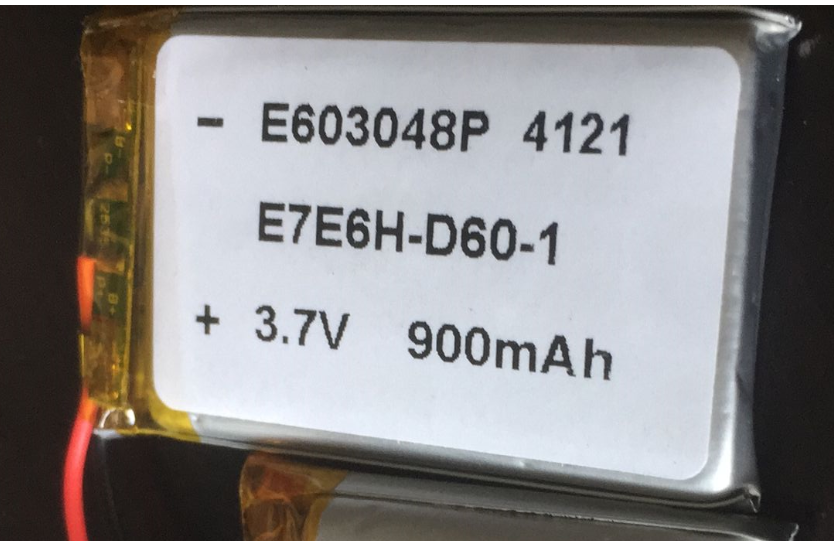
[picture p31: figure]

# BOTÓN

https://www.digikey.es/product-detail/es/nkk-switches/MB2065SB1W01-DA/360-2182-ND/1014878?productid=1014878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

# PANTALLA DISEÑO FINAL

- Displays leds del metro (mirar marca y precio)

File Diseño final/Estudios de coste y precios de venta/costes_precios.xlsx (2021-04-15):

Costes Materiales |  |  |  | Paquetes de venta | Estimación unidades vendidas | Coste/paquetes (€) | Precio Venta sin IVA (€) | IVA (€) | Precio Total (€) | Ingresos
Material | Unidades | Precio | Coste Total | 2 relojes + pantalla | 7500 | 101.86 € | 142.60 € | 29.95 € | 172.54 € | 1294080.48 €
Relojes | 22500 | 19.00 € | 427500.00 € | 2 relojes extra | 1250 | 51.86 € | 72.60 € | 15.25 € | 87.84 € | 109805.08 €
Pantallas | 7500 | 50.00 € | 375000.00 € | 4 relojes | 1250 | 89.86 € | 125.80 € | 26.42 € | 152.22 € | 190270.08 €
Embalajes | 10000 | 1.00 € | 10000.00 € | Total: | 10000 |  |  |  |  | 1594155.64 €
Coworking(anual) |  |  | 5000.00 €
Total Gastos Materiales: |  |  | 817500.00 €
 |  |  |  | Margen de beneficio |  | 40%
 |  |  |  | IVA |  | 21.00%
Cargar Programas
Relojes a cargar: | 22500
Tiempo por reloj (h) | 0.1 |  |  | Gastos Totales (Personales y materiales) |  |  |  | Nº de integrantes en el grupo
Horas de trabajo | 2250 |  |  | 941060.00 € |  |  |  | 5
Precio/hora | 19.36 €
Coste: | 43560.00 € |  |  | BAII (Beneficio Antes de Intereses e Impuestos) |  |  |  | Beneficio por integrante
 |  |  |  | 376424.00 € |  |  |  | 75284.80 €
Embalar |  |  |  | I.S. (Inpuesto de sociedades) |  | Beneficio neto
Paquetes | 10000 |  |  | 15.00% |  | 376424.00 €
Tiempo por paquete (h) | 0.5 |  |  | 15 % sobre el beneficio en los 2 primeros años fiscales
Horas de trabajo | 5000
Precio/hora | 16.00 €
Coste | 80000.00 €
Total costes Personales: | 123560.00 €
Envíos (a cargo del cliente)
Nacional | 4.75 €
Internacional | 10.00 €

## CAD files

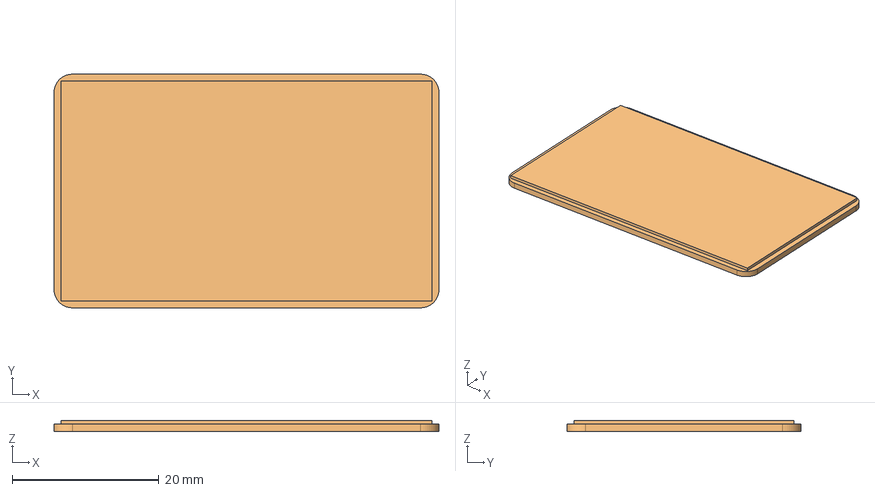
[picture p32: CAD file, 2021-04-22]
Prototipo/Piezas impresión 3D/FreeCad files (FCStd)/tapa_reloj.FCStd
52.4 x 31.8 x 1.50 mm

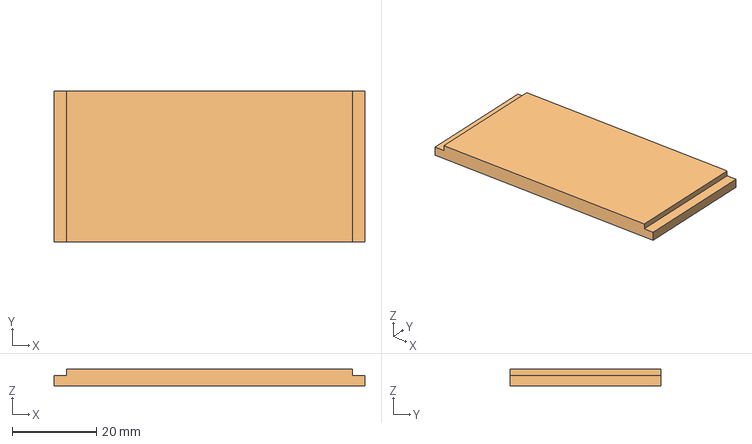
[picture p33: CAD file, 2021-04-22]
Prototipo/Piezas impresión 3D/FreeCad files (FCStd)/tapa_marcador.FCStd
74.0 x 36.0 x 4.00 mm

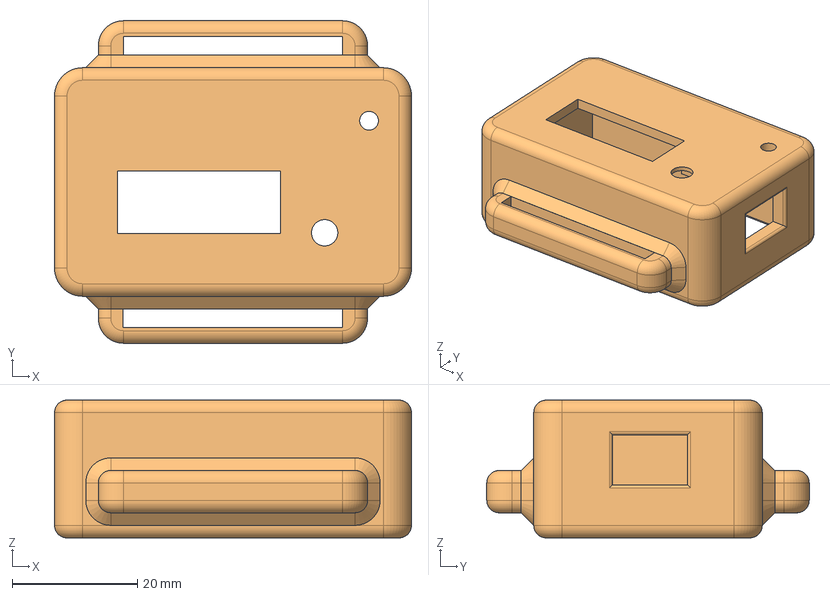
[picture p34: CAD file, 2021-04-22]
Prototipo/Piezas impresión 3D/FreeCad files (FCStd)/carcasa_reloj.FCStd
57.0 x 51.5 x 22.0 mm

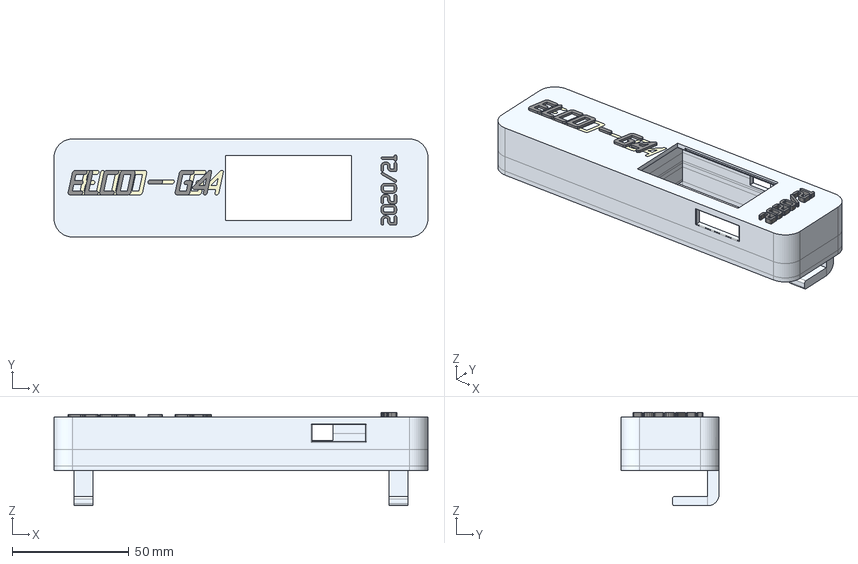
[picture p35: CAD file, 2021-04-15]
Prototipo/Piezas impresión 3D/FreeCad files (FCStd)/carcasa_marcador.FCStd
160.0 x 42.0 x 40.0 mm
ReferenceShapeString

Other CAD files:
Prototipo/Piezas impresión 3D/STL files/carcasa_marcador.stl
Prototipo/Piezas impresión 3D/STL files/carcasa_reloj.stl
Prototipo/Piezas impresión 3D/STL files/tapa_marcador.stl
Prototipo/Piezas impresión 3D/STL files/tapa_reloj.stl

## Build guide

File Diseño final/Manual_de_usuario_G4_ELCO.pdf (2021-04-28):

## Grupo 4 - ELCO

# MANUAL DE USUARIO

## SERVICIO TECNICO: ´

Javier Lopez Iniesta D ´ | íaz del Campo

Inigo Montesino Sarmiento ˜

Fernando García Gutierrez ´

Ivan Martín Canton´

Luis de Pablo Beltran´

Padel Watch

## Índice

1. Introducción | 2
2. Servicios | 2
3. Advertencia de seguridad | 2
4. Especificaciones técnicas del reloj | 3
5. Especificaciones técnicas del marcador | 5
6. Contenido del paquete | 5
7. Instalación rápida | 6
8. Funcionamiento | 7
9. Soluciones a preguntas/problemas frecuentes | 7

## 1. Introducción

Gracias por nuestro producto Padel Watch. Le recomendamos que proceda a leerse el siguiente documento antes de empezar a usarlo para no tener problemas en cuanto a su funcionamiento y su mantenimiento. Guarde su manual en un lugar en el que lo tenga fácilmente localizable en caso de ser necesitado.

## 2. Servicios

Si en algún momento el producto no cumple con sus especificaciones o sus prestaciones, o simplemente no consigue hacerlo funcionar, no dude en ponerse en contacto con nosotros a través de nuestra pagina web o telefono.

https://padel-watch.webnode.es/

## 3. Advertencia de seguridad

1. Se recomienda realizar una carga completa del producto antes del primer uso.
2. Con el fin de mantener el mejor rendimiento, se aconseja realizar una carga completa como mínimo cada tres meses.
3. Si conecta la batería a una toma de corriente, compruebe que el voltaje es el correcto.
4. No almacene el producto cerca de fuentes de calor ni lo deje dentro de un vehículo sin supervisión. El exceso de calor puede causar la explosión de la batería.
5. No exponga el producto a la lluvia o la humedad excesiva.
6. Evite golpes y caídas ya que pueden dañar el producto.
7. No abra ni modifique el producto ya que puede estropearse.

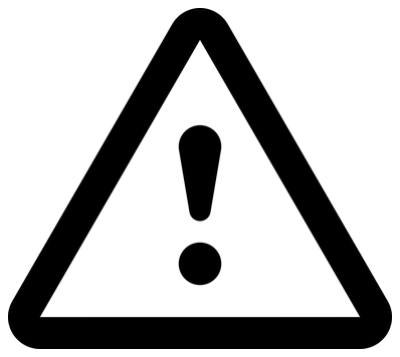
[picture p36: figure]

## 4. Especificaciones técnicas del reloj

Marca: LilyGO

Modelo: TTGO T-Watch-2020

Color: Negro

Tecnología de pantalla: LCD

Tamaño pantalla: 1,54 pulgadas

Resolución pantalla: 240 x 240 pixels.

Fuente de alimentación: Micro USB (5V/1A)

Tipo de conexión inalámbrica: Bluetooth, 802.11a/b/g/n,

Especificaciones WiFi: Estándar: FCC/CE-RED/IC/TELEC/KCC/SRRC/NCC, con protocolo 802.11 b/g/n (802.11n, velocidad de hasta 150 Mbps) A-MPDU y A-MSDU polimerización, soporta intervalo de protección de 0, 4µS.

Rango de frecuencia: 2,4 GHz 2,5 GHz (2400 m 2483,5 m)

Peso: 119 gramos

Batería: 1 batería de litio, 3,7 V, 350 mAh

Temperatura de trabajo: -40℃ a +85℃

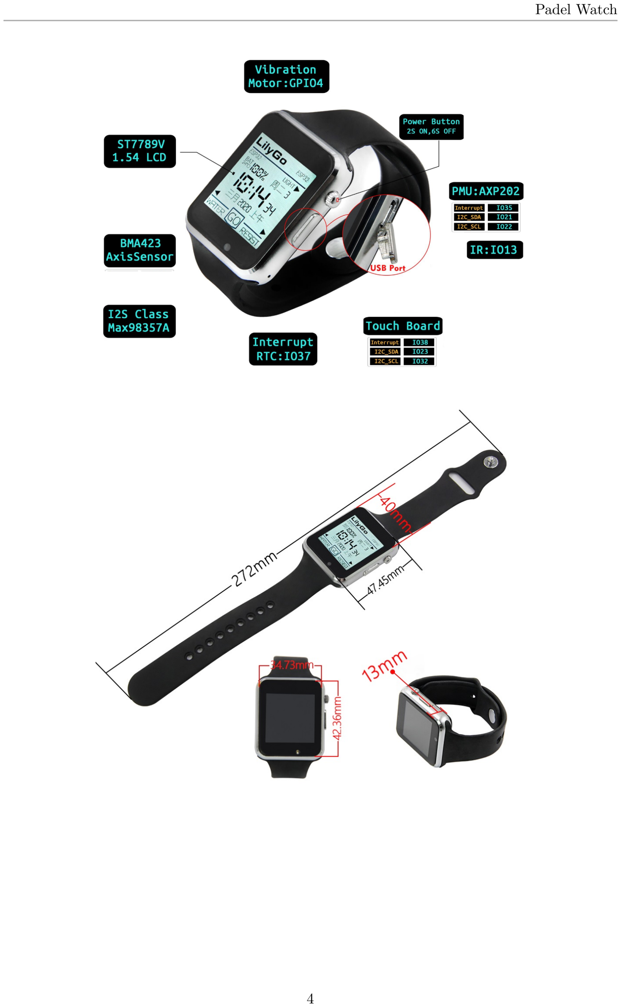
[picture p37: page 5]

## 5. Especificaciones técnicas del marcador

Marca: VEVOR

Dimensiones: 38”x6.5”(100x20cm)

Color: Negro

Voltaje:100-240V

Resolución de Píxeles: 96 x 16 plano

Material: aleación de aluminio, plástico

Número de Perlas de Lámpara: 1536

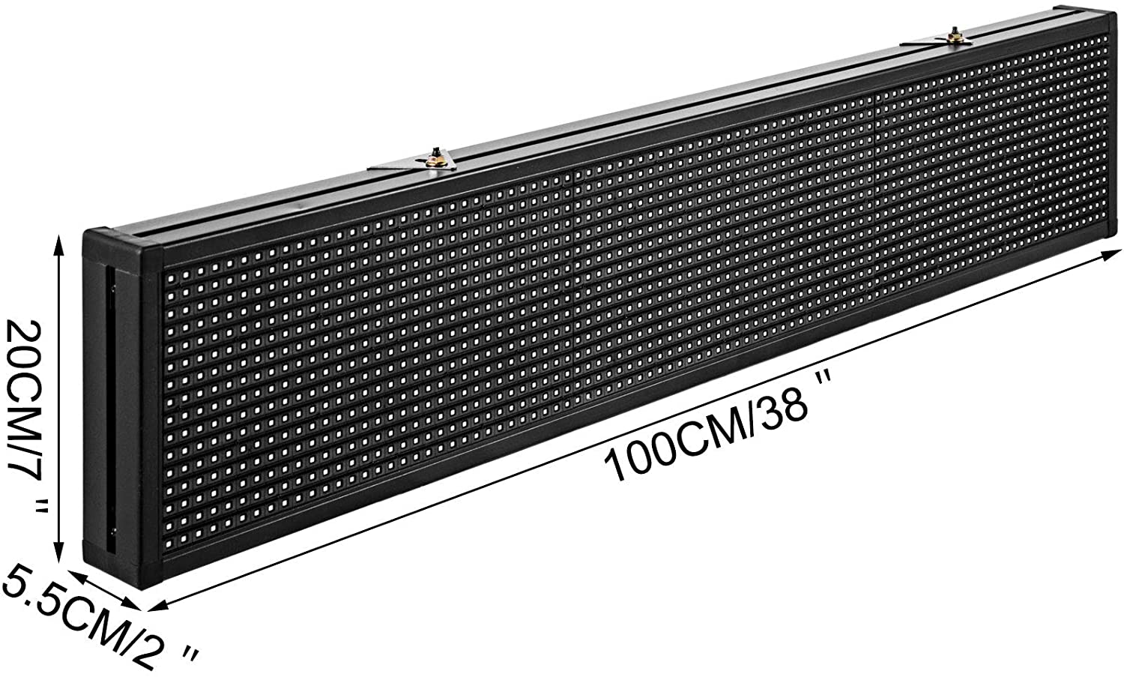
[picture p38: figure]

## 6. Contenido del paquete

Según el producto que haya comprado, la caja puede contener: 2 relojes, 2 relojes y una pantalla o 4 relojes. A su vez, cada reloj vendrá con:

1 X T-Watch-2020

1 X Micro USB Charging Cable

La pantalla vendrá con:

1 x Alimentación USB

1 x Cadena de Gancho

2 x Tornillos de Fijación

1 x Manual

## 7. Instalación rápida

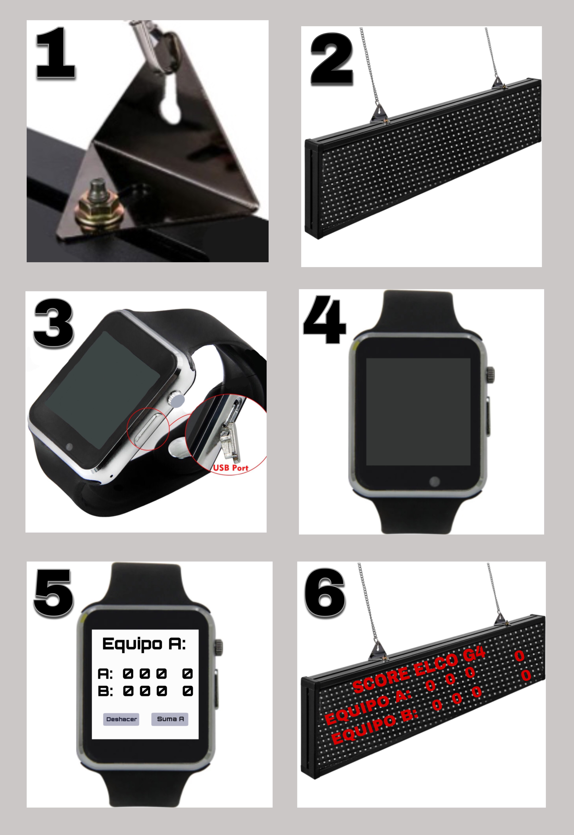
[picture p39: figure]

## 8. Funcionamiento

1. Presione por 3 segundos el “botón de encendido” para encender el reloj. Realice este procedimiento en todos los relojes simultáneamente.
2. Los relojes se sincronizarán automáticamente. Posteriormente deslice hacia la izquierda en cualquiera de ellos para ingresar en el menú de nuevo partido.
3. Mantenga pulsado el botón de encendido del marcador durante 3 segundos para sincronizar adicionalmente el marcador. Si no dispone de marcador omita este paso.
4. Verifique que tanto el reloj como el marcador muestran la puntuación de un nuevo partido.
5. ¡Es el momento de jugar! Cada vez que anote un punto apriete el botón en pantalla de ”sumar punto”.
6. Si se equivoca pulsando puede deshacer el punto anterior apretando el botón en pantalla ”deshacer punto”.
7. Tras finalizar el partido, vuelva a apretar el ”botón de encendido”para apagar todos sus dispositivos y guárdelos en su caja original.

## 9. Soluciones a preguntas/problemas frecuentes

¿Los puntos no se suben correctamente al marcador?
- Comprueba que los diapositivas están correctamente emparejados. En caso contrario póngase en contacto con el servicio técnico de la compañía.

Me he equivocado al incrementar los puntos, ¿puedo deshacer el incremento?
- Si, cada reloj cuenta con un botón para deshacer el punto en caso de error.

¿Se pueden incrementar desde un mismo reloj los puntos de ambas parejas?
- No, cada reloj permite incrementar únicamente los puntos de una pareja.

¿Cual es la garantía del producto?
- La garantía del producto cubre cual fallo técnico y desperfecto de fabricación durante los primeros 24 meses desde la compra del producto. Desde Padel Watch no nos hacemos responsables de cualquier desperfecto ocasionado por el cliente.

¿Existe algún problema si el reloj recibe salpicaduras de sudor?
- En absoluto, el reloj está diseñado para practicar deporte con él. Puede recibir ciertas gotas pero es recomendable que tras su uso se seque.

¿Puede recibir impactos?
- Como reloj deportivo, es relativamente resistente a movimientos bruscos y agitaciones, pero ha de tener especialmente cuidado con los impactos fuertes y directos en la zona de la pantalla. Por ello recomendamos que el reloj se coloque en la mano menos hábil.

Acceda a nuestra página web para más información.

https://padel-watch.webnode.es/

Padel Watch es una marca registrada creada para la asignatura de ELCO. Otras marcas registradas son propiedad de sus respectivos autores. Especificaciones sujetas a cambios sin previo aviso.

Diseñado en España.
Copyright ©2021 Padel Watch. All rights reserved.

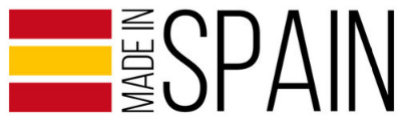
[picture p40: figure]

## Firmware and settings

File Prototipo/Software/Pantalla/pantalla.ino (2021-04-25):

/**
*	Pantalla marcador de padel, versión del LILYGO TTGO T5 V2.3 ESP32
*	
*	Autores:
*		Fernando Garcia Gutierrez
*		Javier Lopez Iniesta
*		Ivan Martin Canton
*		Iñigo Montesino Sarmiento
*		Luis de Pablo Beltran
**/

// Se define la version de nuestra pantalla
#define LILYGO_T5_V213

#include <boards.h>
#include <GxEPD.h>
#include <SD.h>
#include <FS.h>
#include <esp_now.h>

// Se incluyen las libreria de nuestro modelo
#include <GxGDEH0213B73/GxGDEH0213B73.h>  // 2.13" b/w old panel
#include GxEPD_BitmapExamples

// FreeFonts de Adafruit_GFX
#include <Fonts/FreeMonoBold9pt7b.h>
#include <Fonts/FreeMonoBold12pt7b.h>
#include <Fonts/FreeMonoBold18pt7b.h>
#include <Fonts/FreeMonoBold24pt7b.h>
#include <GxIO/GxIO_SPI/GxIO_SPI.h>
#include <GxIO/GxIO.h>
#include <WiFi.h>

GxIO_Class io(SPI,  EPD_CS, EPD_DC,  EPD_RSET);
GxEPD_Class display(io, EPD_RSET, EPD_BUSY);

// Se definen las variables para almacenar la puntuación de los equipos.
int set1A = 0;
int set2A = 0;
int set3A = 0;
int set1B = 0;
int set2B = 0;
int set3B = 0;
int puntA = 0;
int puntB = 0;

// Se crean las variables para representar la puntuación en pantalla del marcador.
String puntA_pantalla ; // 0 15 30 40
String puntB_pantalla ; // 0 15 30 40

// Se crean las variables que controlan el funcionamiento del marcador.
int set = 1; // set 1, 2, 3
boolean tie = false;
boolean winA = false;
boolean winB = false;

/* Se crea una estructura que almacena cuando se pulsan los mensajes para poder realizar 
la comunicacion con el resto de dispositivos
*/
typedef struct struct_message {
  int puntEnvA;
  int puntEnvB;
} struct_message;

struct_message myData;

// Funcion que almacena los valores recibidos en una constante de tipo struct_message
void OnDataRecv(const uint8_t * mac, const uint8_t *incomingData, int len) {
  memcpy(&myData, incomingData, sizeof(myData));
  Serial.println(myData.puntEnvA);
  Serial.println(myData.puntEnvB);
}

/* Funcion que cuando es llamada, aumenta un juego al equipo A en funcion del set en el que 
se encuentren.
*/
void addjuegoA() {
  if (set == 1) {
    set1A ++;
  }
  else if (set == 2) {
    set2A ++;
  }
  else {
    set3A ++;
  }
}

/* Funcion que cuando es llamada, aumenta un juego al equipo B en funcion del set en el que se 
encuentren.
*/
void addjuegoB() {
  if (set == 1) {
    set1B ++;
  }
  else if (set == 2) {
    set2B ++;
  }
  else {
    set3B ++;
  }
}

// Funcion que cuando es llamada, suma un punto al equipo A.
void addPuntA() {

  // Se suma un punto al equipo A.
  puntA ++;
  
  /* Se reinicia el valor de la variable que indica que el equipo A ha ganado un punto para 
  poder detectar el siguiente cambio
  */
  myData.puntEnvA = 0;

  /* Solo añade un juego si el equipo A tiene mas de 3 puntos (o de 7 si estan en tie break) 
  y una diferencia de 2 puntos frente al equipo B.
  */
  if (tie == false ) {
    if ((puntA > 3) && (puntA - puntB >= 2)) {
      addjuegoA();
      puntA = 0;
      puntB = 0;
    }
  }  else if (tie == true) {
    if ((puntA >= 7 ) && (puntA - puntB >= 2) ) {
      addjuegoA();
      puntA = 0;
      puntB = 0;
    }
  }
  
  /* Si se encuentra en el primer set y el equipo A tiene mas de 6 juegos y hay una diferencia 
  de 2 o más juegos entre los dos (o si tiene 7 juegos para el tie break), suma un set y tie 
  pasa a valer falso. Si los dos llegan a 6 juegos, tie pasa a valer true.
  */
  if (set == 1) {
    if ((set1A >= 6 && ((set1A - set1B) >= 2)) || set1A == 7) {
      set ++;
      tie  = false;
    }
    else if ((set1A == 6) && (set1B == 6)) {
      tie = true;
    }
  }
  
  /* Exactamente igual que en el set anterior, pero si detecta además que el equipo A ganó 
  el set anterior, el equipo A gana.
  */
  if (set == 2) {
    if ((set2A >= 6 && ((set2A - set2B) >= 2)) || set2A == 7) {
      if (set1A > set1B) {
        winA = true;
      } else {
        set ++;
        tie  = false;
      }
    }
    else if ((set2A == 6) && (set2B == 6)) {
      tie = true;
    }
  }
  
  /* Exactamente igual que el set anterior, pero comprobando el set 1 y el 2 para poder dar la 
  victoria al equipo A.
  */
  if (set == 3) {
    if ((set3A >= 6 && ((set3A - set3B) >= 2)) || set3A == 7) {
      if (set1A > set1B || set2A > set2B) {
        winA = true;
      } else {
        set ++;
        tie  = false;
      }
    }
    else if ((set3A == 6) && (set3B == 6)) {
      tie = true;
    }
  }
}

// Funcion que cuando es llamada, suma un punto al equipo B.
void addPuntB() {

  // Se suma un punto al equipo B
  puntB ++;
  
  /* Se reinicia el valor de la variable que indica que el equipo B ha ganado un punto para 
  poder detectar el siguiente cambio
  */
  myData.puntEnvB = 0;

  /* Solo añade un juego si el equipo B tiene mas de 3 puntos (o de 7 si estan en tie break) y 
  una diferencia de 2 puntos frente al equipo A.
  */
  if (tie == false ) {
    if (( puntB > 3) && (puntB - puntA >= 2)) {
      addjuegoB();
      puntA = 0;
      puntB = 0;
    }
  }  else if (tie == true) {
    if ((puntB >= 7 ) && (puntB - puntA >= 2) ) {
      addjuegoB();
      puntA = 0;
      puntB = 0;
    }
  }
  
  /* Si se encuentra en el primer set y el equipo B tiene mas de 6 juegos y hay una 
  diferencia de 2 o más juegos entre los dos (o si tiene 7 juegos para el tie break), 
  suma un set y tie pasa a valer falso. Si los dos llegan a 6 juegos, tie pasa a valer true.
  */
  if (set == 1) {
    if ((set1B >= 6 && ((set1B - set1A) >= 2)) || set1B == 7) {
      set ++;
      tie  = false;
    }
    else if ((set1A == 6) && (set1B == 6)) {
      tie = true;
    }
  }
  
  /* Exactamente igual que en el set anterior, pero si detecta además que el equipo B ganó el 
  set anterior, el equipo A pierde.
  */
  if (set == 2) {
    if ((set2B >= 6 && ((set2B - set2A) >= 2)) || set2B == 7) {
      if (set1B > set1A) {
        winB = true;
      } else {
        set ++;
        tie  = false;
      }
    }
    else if ((set2A == 6) && (set2B == 6)) {
      tie = true;

    }
  }
  
  /* Exactamente igual que el set anterior, pero comprobando el set 1 y el 2 para poder dar 
  la victoria al equipo B.
  */
  if (set == 3) {
    if ((set3B >= 6 && ((set3B - set3A) >= 2)) || set3B == 7) {
      if (set1B > set1A || set2B > set2A) {
        winB = true;
      } else {
        set ++;
        tie  = false;
      }
    }
    else if ((set3A == 6) && (set3B == 6)) {
      tie = true;
    }
  }
}

// Funcion que pinta en la pantalla la puntuacion de la partida y el resultado final.
void printResultado() {
	
  /* Se convierten las variables a la puntuacion de padel en funcion de si se encuentran 
  en tie break o no.
  */
  if (tie == false) {
    if (puntA == 0) {
      puntA_pantalla = "0";
    }
    else if (puntA == 1) {
      puntA_pantalla = "15";
    }
    else if (puntA == 2) {
      puntA_pantalla = "30";
    }
    else if (puntA == 3) {
      puntA_pantalla = "40";
    }
    else if ((puntA > 3) && (puntA == puntB)) {
      puntA_pantalla = "40";
    }
    else if ((puntA > 3) && (puntA > puntB)) {
      puntA_pantalla = "AD";
    }

    if (puntB == 0) {
      puntB_pantalla = "0";
    }
    else if (puntB == 1) {
      puntB_pantalla = "15";
    }
    else if (puntB == 2) {
      puntB_pantalla = "30";
    }
    else if (puntB == 3) {
      puntB_pantalla = "40";
    }
    else if ((puntB > 3) && (puntA == puntB)) {
      puntB_pantalla = "40";
    }
    else if ((puntB > 3) && (puntA < puntB)) {
      puntB_pantalla = "AD";
    }
	
  } else {
    puntA_pantalla = (String) puntA;
    puntB_pantalla = (String) puntB;
  }

  // Se pinta la puntuacion mientras no se haya acabado la partida.
  if (winA == false && winB == false) {
    display.setFont(&FreeMonoBold12pt7b);
    display.setCursor(40, 20);
    display.println("SCORE ELCO G4");
    display.setFont(&FreeMonoBold18pt7b);
    display.setCursor(0, 60);
    display.println("A:");
    display.setCursor(50, 60);
    display.println(set1A);
    display.setCursor(80, 60);
    display.println(set2A);
    display.setCursor(110, 60);
    display.println(set3A);
    display.setCursor(0, 100);
    display.println("B:");
    display.setCursor(50, 100);
    display.println(set1B);
    display.setCursor(80, 100);
    display.println(set2B);
    display.setCursor(110, 100);
    display.println(set3B);
    display.setCursor(170, 60);
    display.println(puntA_pantalla);
    display.setCursor(170, 100);
    display.println(puntB_pantalla);
	
  } 
  
  //Se pinta la pantalla de victora o derrota en funcion del resultado final.
  else if (winA == true) {
    display.setFont(&FreeMonoBold12pt7b);
    display.setCursor(40, 20);
    display.println("SCORE ELCO G4");
    display.setCursor(0, 60);
    display.println( "Ha ganado el");
    display.setCursor(0, 80);
    display.println( "Equipo A");
	
  } 
  else if (winB == true) {
    display.setFont(&FreeMonoBold12pt7b);
    display.setCursor(40, 20);
    display.println("SCORE ELCO G4");
    display.setCursor(0, 60);
    display.println( "Ha ganado el ");
    display.setCursor(0, 80);
    display.println( "Equipo B");
  }
}

// Funcion que se ejecuta al comenzar el programa.
void setup(void) {
  
  //Se habilita el puerto serie, el WiFi y la pantalla
  Serial.begin(115200);
  Serial.println();
  Serial.println("setup");
  SPI.begin(EPD_SCLK, EPD_MISO, EPD_MOSI);
  display.init(); // enable diagnostic output on Serial
  Serial.println("setup done");
  WiFi.mode(WIFI_MODE_STA);
  
  if (esp_now_init() != ESP_OK) {
    Serial.println("Error initializing ESP-NOW");
    return;
  }
  
  esp_now_register_recv_cb(OnDataRecv);
}

// Función que se activa continuamente en bucle.
void loop() {
	
  /* Si se detecta que el equipo A o B ha conseguido un punto, se suma 
  un punto al equipo A o B respectivamente.
  */
  if (myData.puntEnvB == 1) {
    addPuntB();
  }
  if (myData.puntEnvA == 1) {
    addPuntA();
  }
  
  // Se borra la pantalla y se vuelve a pintar con los resultados actualizados.
  display.setTextColor(GxEPD_BLACK);
  display.setRotation(1);
  display.fillScreen(GxEPD_WHITE);
  printResultado();
  display.updateWindow(0, 0, GxEPD_WIDTH, GxEPD_HEIGHT, false);
}

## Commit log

2021-04-15 file v1
    [carcasa_marcador.FCStd, carcasa_marcador.stl, costes_precios.xlsx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]
2021-04-16 carcasa marcador modificada
    [carcasa_marcador.stl]
2021-04-22 avances version casi definitiva
    [carcasa_marcador.stl, carcasa_reloj.FCStd, carcasa_reloj.stl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]
